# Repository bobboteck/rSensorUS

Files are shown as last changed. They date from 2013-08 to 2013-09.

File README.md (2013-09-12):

rSensorUS
=========

rSensorUS is a board for control up to 8 HC-SR04 Ultrasonic ranging modules based on Microchip PIC 18F2620.

The board have two analog input and one I2C master port, theoretically will be used to connect a temperature and humidity sensors, with the purpose of compensate the measurements of the ultrasonic sensors.

the communication with master controller can take place via serial TTL or RS-485.

The power voltage is 5 Volt.

Software develop used
======================
Currently the electric schema and the PCB was designed with Eagle 6.4 version, by CADSoft

For the code currently used MPLAB X version 1.90 and XC8 version 1.20, by Microchip

Now
====
Actualy working on Branch "Communication" to implement the Serial communication and protocol to mange the message and command received from Master

More info
==========
You can see more info on project in the wiki section

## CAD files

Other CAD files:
Code/rSensorUS.X/l.obj

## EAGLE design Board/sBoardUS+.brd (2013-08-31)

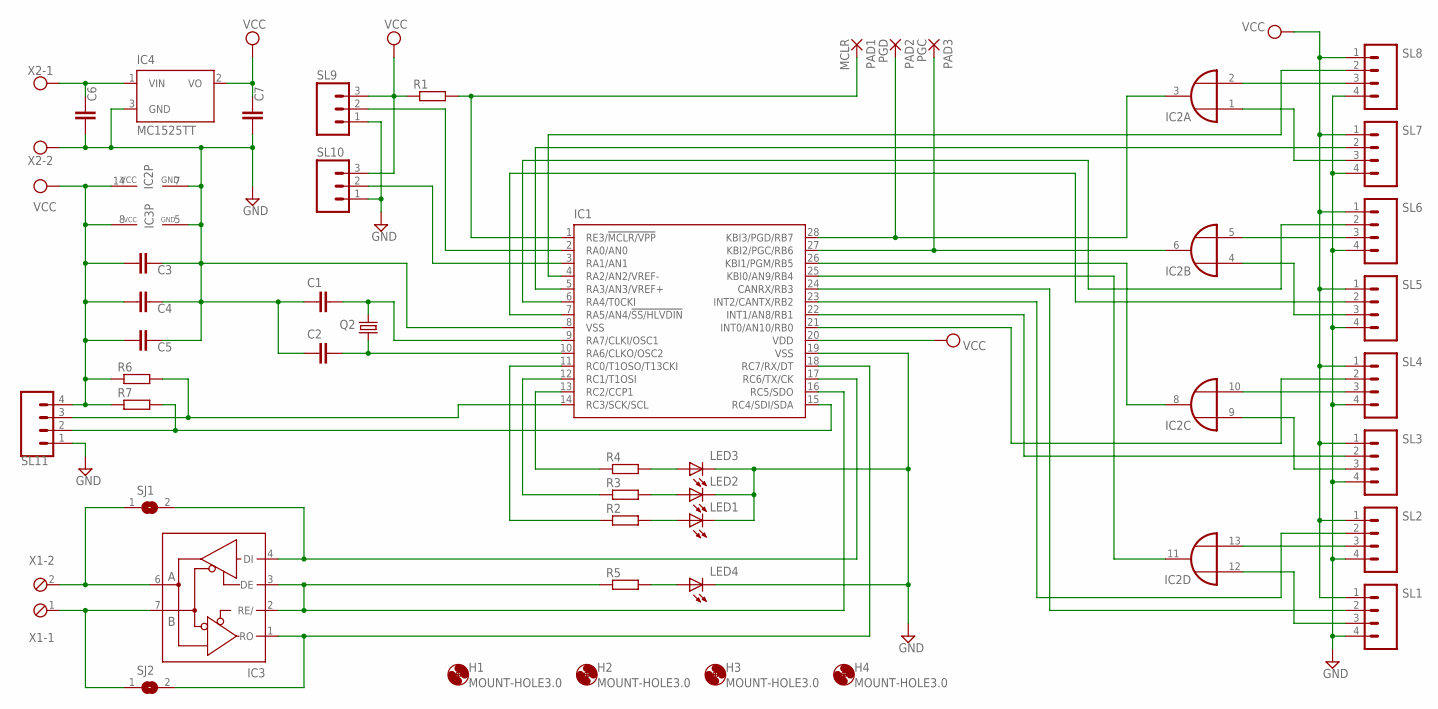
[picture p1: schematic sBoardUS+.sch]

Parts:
C1, C2, C3, C4, C5, C6, C7: C-EUC0805; C0805
H1, H2, H3, H4: MOUNT-HOLE3.0; 3,0
IC1: PIC18F2580-E/SO; SO28W
IC2: 74AC32D; SO14
IC3: MAX481CSA; SO08
IC4: MC1525TT; SOT23
LED1, LED2, LED3, LED4: LED; SMARTLED-TTW
PAD1: MCLR; SMD1,27-2,54
PAD2: PGD; SMD1,27-2,54
PAD3: PGC; SMD1,27-2,54
Q2: CRYSTALHC49U-V; HC49U-V
R1, R2, R3, R4, R5, R6, R7: R-EU_R0805; R0805
SJ1, SJ2: SJ
SL1, SL2, SL3, SL4, SL5, SL6, SL7, SL8, SL11: M04; 04P
SL9, SL10: M03; 03P
X1: MPT2; 2POL254
X2: AK500/2

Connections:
GND: C1.1, C2.1, C3.1, C4.1, C5.1, C6.2, C7.2, IC1.8 (VSS), IC1.19 (VSS), IC2.7 (GND), IC3.5 (GND), IC4.3 (GND), LED1.C@1 (C), LED2.C@1 (C), LED3.C@1 (C), LED4.C@1 (C), SL1.4, SL2.4, SL3.4, SL4.4, SL5.4, SL6.4, SL7.4, SL8.4, SL9.1, SL10.1, SL11.1, X2.2
unnamed: C1.2, IC1.9 (RA7/CLKI/OSC1), Q2.2
unnamed: C2.2, IC1.10 (RA6/CLKO/OSC2), Q2.1
unnamed: IC2.2 (I1), SL8.3
unnamed: IC1.1 (RE3/!MCLR/VPP), PAD1.1, R1.2
unnamed: IC1.2 (RA0/AN0), SL9.2
unnamed: IC1.3 (RA1/AN1), SL10.2
unnamed: IC1.25 (KBI0/AN9/RB4), IC2.11 (O)
unnamed: IC1.26 (KBI1/PGM/RB5), IC2.8 (O)
unnamed: IC1.27 (KBI2/PGC/RB6), IC2.6 (O), PAD3.1
unnamed: IC1.28 (KBI3/PGD/RB7), IC2.3 (O), PAD2.1
unnamed: IC2.5 (I1), SL6.3
unnamed: IC2.10 (I1), SL4.3
unnamed: IC2.13 (I1), SL2.3
unnamed: IC2.1 (I0), SL7.3
unnamed: IC2.4 (I0), SL5.3
unnamed: IC2.9 (I0), SL3.3
unnamed: IC2.12 (I0), SL1.3
unnamed: IC1.22 (INT1/AN8/RB1), SL3.2
unnamed: IC1.5 (RA3/AN3/VREF+), SL7.2
unnamed: IC1.4 (RA2/AN2/VREF-), SL8.2
unnamed: IC1.6 (RA4/T0CKI), SL6.2
unnamed: IC1.7 (RA5/AN4/!SS/HLVDIN), SL5.2
unnamed: IC1.21 (INT0/AN10/RB0), SL4.2
unnamed: IC1.24 (CANRX/RB3), SL1.2
unnamed: IC3.6 (A), SJ1.1, X1.2
unnamed: IC3.7 (B), SJ2.1, X1.1
unnamed: IC1.16 (RC5/SDO), IC3.2 (RE/), IC3.3 (DE), R5.1
unnamed: IC1.17 (RC6/TX/CK), IC3.4 (DI), SJ1.2
unnamed: IC1.18 (RC7/RX/DT), IC3.1 (RO), SJ2.2
unnamed: IC1.23 (INT2/CANTX/RB2), SL2.2
unnamed: IC1.11 (RC0/T1OSO/T13CKI), R2.1
unnamed: IC1.12 (RC1/T1OSI), R3.1
unnamed: IC1.13 (RC2/CCP1), R4.1
unnamed: LED3.A@1 (A), R4.2
unnamed: LED2.A@1 (A), R3.2
unnamed: LED1.A@1 (A), R2.2
unnamed: C6.1, IC4.1 (VIN), X2.1
unnamed: LED4.A@1 (A), R5.2
unnamed: IC1.14 (RC3/SCK/SCL), R6.2, SL11.3
unnamed: IC1.15 (RC4/SDI/SDA), R7.2, SL11.2
VCC: C3.2, C4.2, C5.2, C7.1, IC1.20 (VDD), IC2.14 (VCC), IC3.8 (VCC), IC4.2 (VO), R1.1, R6.1, R7.1, SL1.1, SL2.1, SL3.1, SL4.1, SL5.1, SL6.1, SL7.1, SL8.1, SL9.3, SL10.3, SL11.4

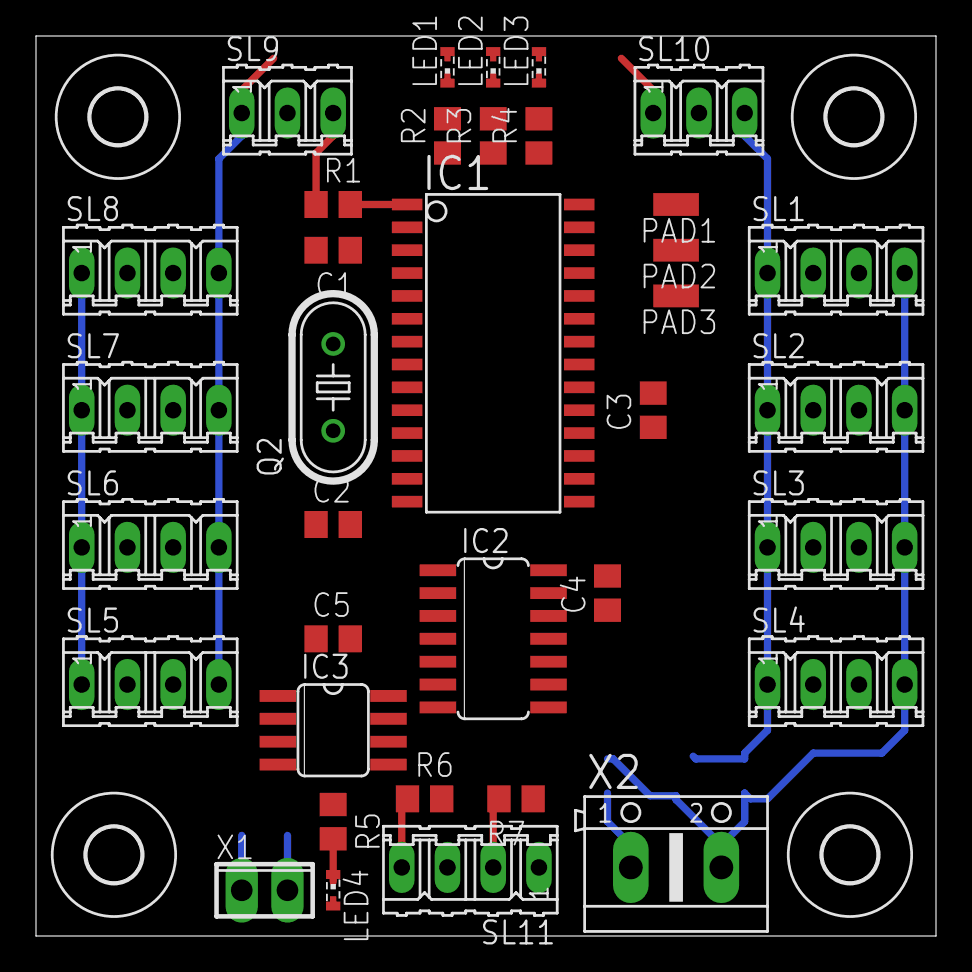
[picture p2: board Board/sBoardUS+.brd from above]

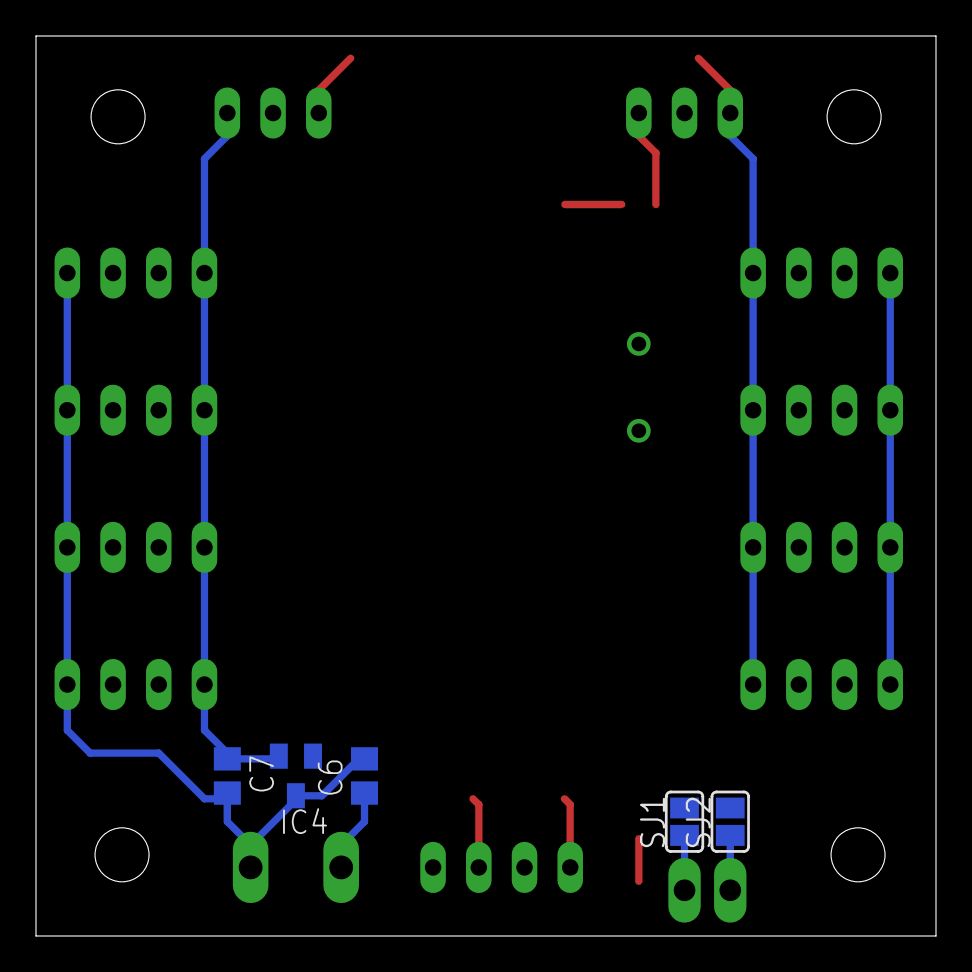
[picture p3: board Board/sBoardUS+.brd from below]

Board: 2 copper layers, 50.0 x 50.0 mm, 45 parts (5 on the bottom side), 42 nets.

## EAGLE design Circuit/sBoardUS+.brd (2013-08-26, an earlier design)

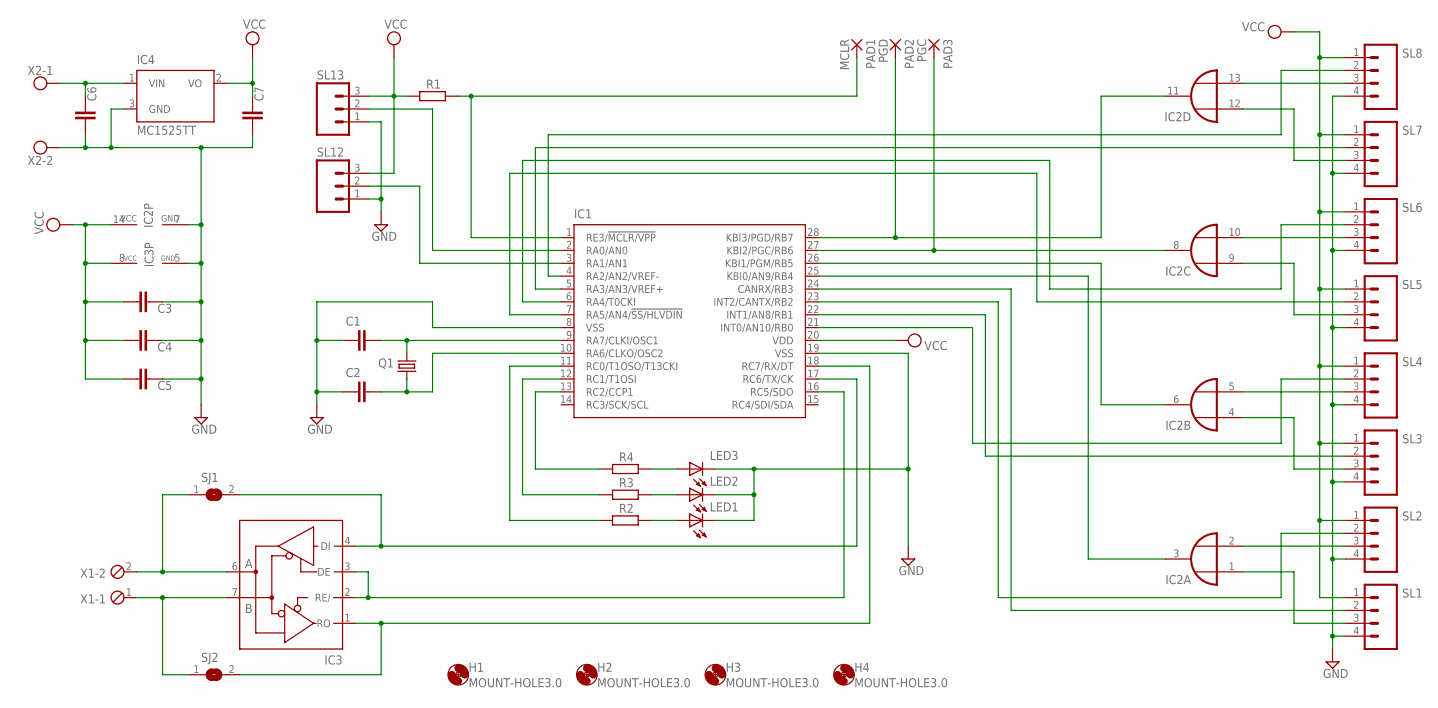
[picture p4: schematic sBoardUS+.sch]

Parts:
C1, C2, C3, C4, C5, C6, C7: C-EUC0805; C0805
H1, H2, H3, H4: MOUNT-HOLE3.0; 3,0
IC1: PIC18F2580-E/SO; SO28W
IC2: 74AC32D; SO14
IC3: MAX481CSA; SO08
IC4: MC1525TT; SOT23
LED1, LED2, LED3: LED; SMARTLED-TTW
PAD1: MCLR; SMD1,27-2,54
PAD2: PGD; SMD1,27-2,54
PAD3: PGC; SMD1,27-2,54
Q1: CRYSTALHC49UP; HC49UP
R1, R2, R3, R4: R-EU_M2012; M2012
SJ1, SJ2: SJ
SL1, SL2, SL3, SL4, SL5, SL6, SL7, SL8: M04; 04P
SL12, SL13: M03; 03P
X1: MPT2; 2POL254
X2: AK500/2

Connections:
GND: C1.1, C2.1, C3.1, C4.1, C5.1, C6.2, C7.2, IC1.8 (VSS), IC1.19 (VSS), IC2.7 (GND), IC3.5 (GND), IC4.3 (GND), LED1.C@1 (C), LED2.C@1 (C), LED3.C@1 (C), SL1.4, SL2.4, SL3.4, SL4.4, SL5.4, SL6.4, SL7.4, SL8.4, SL12.1, SL13.1, X2.2
unnamed: C1.2, IC1.9 (RA7/CLKI/OSC1), Q1.2
unnamed: C2.2, IC1.10 (RA6/CLKO/OSC2), Q1.1
unnamed: IC2.5 (I1), SL4.3
unnamed: IC1.1 (RE3/!MCLR/VPP), PAD1.1, R1.1
unnamed: IC1.2 (RA0/AN0), SL13.2
unnamed: IC1.3 (RA1/AN1), SL12.2
unnamed: IC1.25 (KBI0/AN9/RB4), IC2.3 (O)
unnamed: IC1.26 (KBI1/PGM/RB5), IC2.6 (O)
unnamed: IC1.27 (KBI2/PGC/RB6), IC2.8 (O), PAD3.1
unnamed: IC1.28 (KBI3/PGD/RB7), IC2.11 (O), PAD2.1
unnamed: IC2.2 (I1), SL2.3
unnamed: IC2.13 (I1), SL8.3
unnamed: IC2.10 (I1), SL6.3
unnamed: IC2.12 (I0), SL7.3
unnamed: IC2.9 (I0), SL5.3
unnamed: IC2.4 (I0), SL3.3
unnamed: IC2.1 (I0), SL1.3
unnamed: IC1.22 (INT1/AN8/RB1), SL3.2
unnamed: IC1.5 (RA3/AN3/VREF+), SL7.2
unnamed: IC1.4 (RA2/AN2/VREF-), SL8.2
unnamed: IC1.6 (RA4/T0CKI), SL6.2
unnamed: IC1.7 (RA5/AN4/!SS/HLVDIN), SL5.2
unnamed: IC1.21 (INT0/AN10/RB0), SL4.2
unnamed: IC1.24 (CANRX/RB3), SL1.2
unnamed: IC3.6 (A), SJ1.1, X1.2
unnamed: IC3.7 (B), SJ2.1, X1.1
unnamed: IC1.16 (RC5/SDO), IC3.2 (RE/), IC3.3 (DE)
unnamed: IC1.17 (RC6/TX/CK), IC3.4 (DI), SJ1.2
unnamed: IC1.18 (RC7/RX/DT), IC3.1 (RO), SJ2.2
unnamed: IC1.23 (INT2/CANTX/RB2), SL2.2
unnamed: IC1.11 (RC0/T1OSO/T13CKI), R2.2
unnamed: IC1.12 (RC1/T1OSI), R3.2
unnamed: IC1.13 (RC2/CCP1), R4.2
unnamed: LED3.A@1 (A), R4.1
unnamed: LED2.A@1 (A), R3.1
unnamed: LED1.A@1 (A), R2.1
unnamed: C6.1, IC4.1 (VIN), X2.1
VCC: C3.2, C4.2, C5.2, C7.1, IC1.20 (VDD), IC2.14 (VCC), IC3.8 (VCC), IC4.2 (VO), R1.2, SL1.1, SL2.1, SL3.1, SL4.1, SL5.1, SL6.1, SL7.1, SL8.1, SL12.3, SL13.3

Board: 2 copper layers, 40 parts (3 on the bottom side), 39 nets, no tracks yet.

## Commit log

2013-08-26 Adding schema and board
    Firsth commit of this files
    [sBoardUS+.brd, sBoardUS+.sch]
2013-08-26 Aggiunti i pad per la programmazione ICSP
    [sBoardUS+.brd, sBoardUS+.sch]
2013-08-28 Aggiornamento struttura e modifiche
    Cambiata la cartella di lavoro e ricreato il file BRD, modificato lo
    schema aggiungendo il led di TX/RX, aggiunto il connettore I2C, cambiato
    il quarzo.
    [sBoardUS+.brd, sBoardUS+.sch]
2013-08-28 Approntata disposizione
    Disposizione non definitiva dei componenti, in particolare per quanto
    riguarda i due integrati più piccoli, per il resto dovrebbe essere in un
    configurazione ottimale.
    [sBoardUS+.brd]
2013-08-29 Disegnate alcune piste delle alimentazioni ...
    ... e riposizionati alcuni componenti per evitare intrecci di piste.
    Devo chiedere consiglio per quanto riguarda il posizionamento dei due IC
    secondari, trovare il regolatore definitivo e verificare i condenstatori
    sul regolatore.
    Va anche invertito l'utilizzo delle porte OR in questo modo le piste si
    intrecciano troppo.
    [sBoardUS+.brd]
2013-08-31 Invertite le porte OR per ridurre gli incroci delle piste
    [sBoardUS+.brd, sBoardUS+.sch]
2013-09-04 Aggiunta cartella contenente il codice del progetto
2013-09-05 Aggiornato il file gitignore
    Per escludere file che prevedono impostazioni locali per il progetto
    MPLAB X, ho verificato che in questi cambiano i path tra windows e linux
2013-09-09 Aggiunta liberiria di Settings
    [l.obj]
2013-09-10 Aggiunti i file per la gestione della comunicazione
    Composta da tre strati, Serial gestisce la periferica, Protocol elabora
    i pacchetti ricevuti e da inviare, Parser analizza i dati ricevuti ed
    esegue le istruzioni necessarie per gestirli.
